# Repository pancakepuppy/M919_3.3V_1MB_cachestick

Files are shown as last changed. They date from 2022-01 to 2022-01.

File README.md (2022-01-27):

# M919_3.3V_1MB_cachestick
A 3.3V 1MB cache stick design for PCChips M919

(This design is only to be used with 3.3V processors. 5V/4V CPUs will violate the Absolute Maximum Terminal Voltage Relative to GND of the 3.3V SRAM chips which will likely result in permanent damage of the cache ICs.)

Design uses center power 0.400" 32-SOJ 128Kx8 3.3V SRAMs, which are available in speed grades of 8(less common)/10/12/15ns from several vendors. 
These parts should all fit this criteria:

71V124SA10/12/15Y

CY7C1019DV33-10VXI

CY7C1019BV33-10/12/15V

CY7C1019CV33-10/12/15V

IS63LV1024-8/10/12K

AS7C31025B-10/12/15J

AS7C31025C-10J

Bill of materials only has 3 different parts on it:

  Qty 18 - 0603 0.1uF 6.3V+ ceramic capacitors
  
  Qty 9 - SRAM parts as described above
  
  Qty 4 - 0603 33ohm convex 4resistor array
  
If you're experienced at hand soldering, the module is buildable this way (that's how I've built mine so far!)

I've been testing the module design with a 5x86-P75 (133MHz) at fastest L2 and DRAM settings and it has been very stable, running a number of DOS and Win95 benchmarks and tests (such as Quake, Doom, cachechk, Winstone 96, CPUmark99, Super PI) with no issues. 

If you want to have boards made with JLCPCB, upload the "UPLOAD_THIS_ZIP.zip" file in the /plotted_JLCsettings/ directory. It has the gerbers and drill files with their recommended plotting settings. Otherwise, plot however your board house recommends!

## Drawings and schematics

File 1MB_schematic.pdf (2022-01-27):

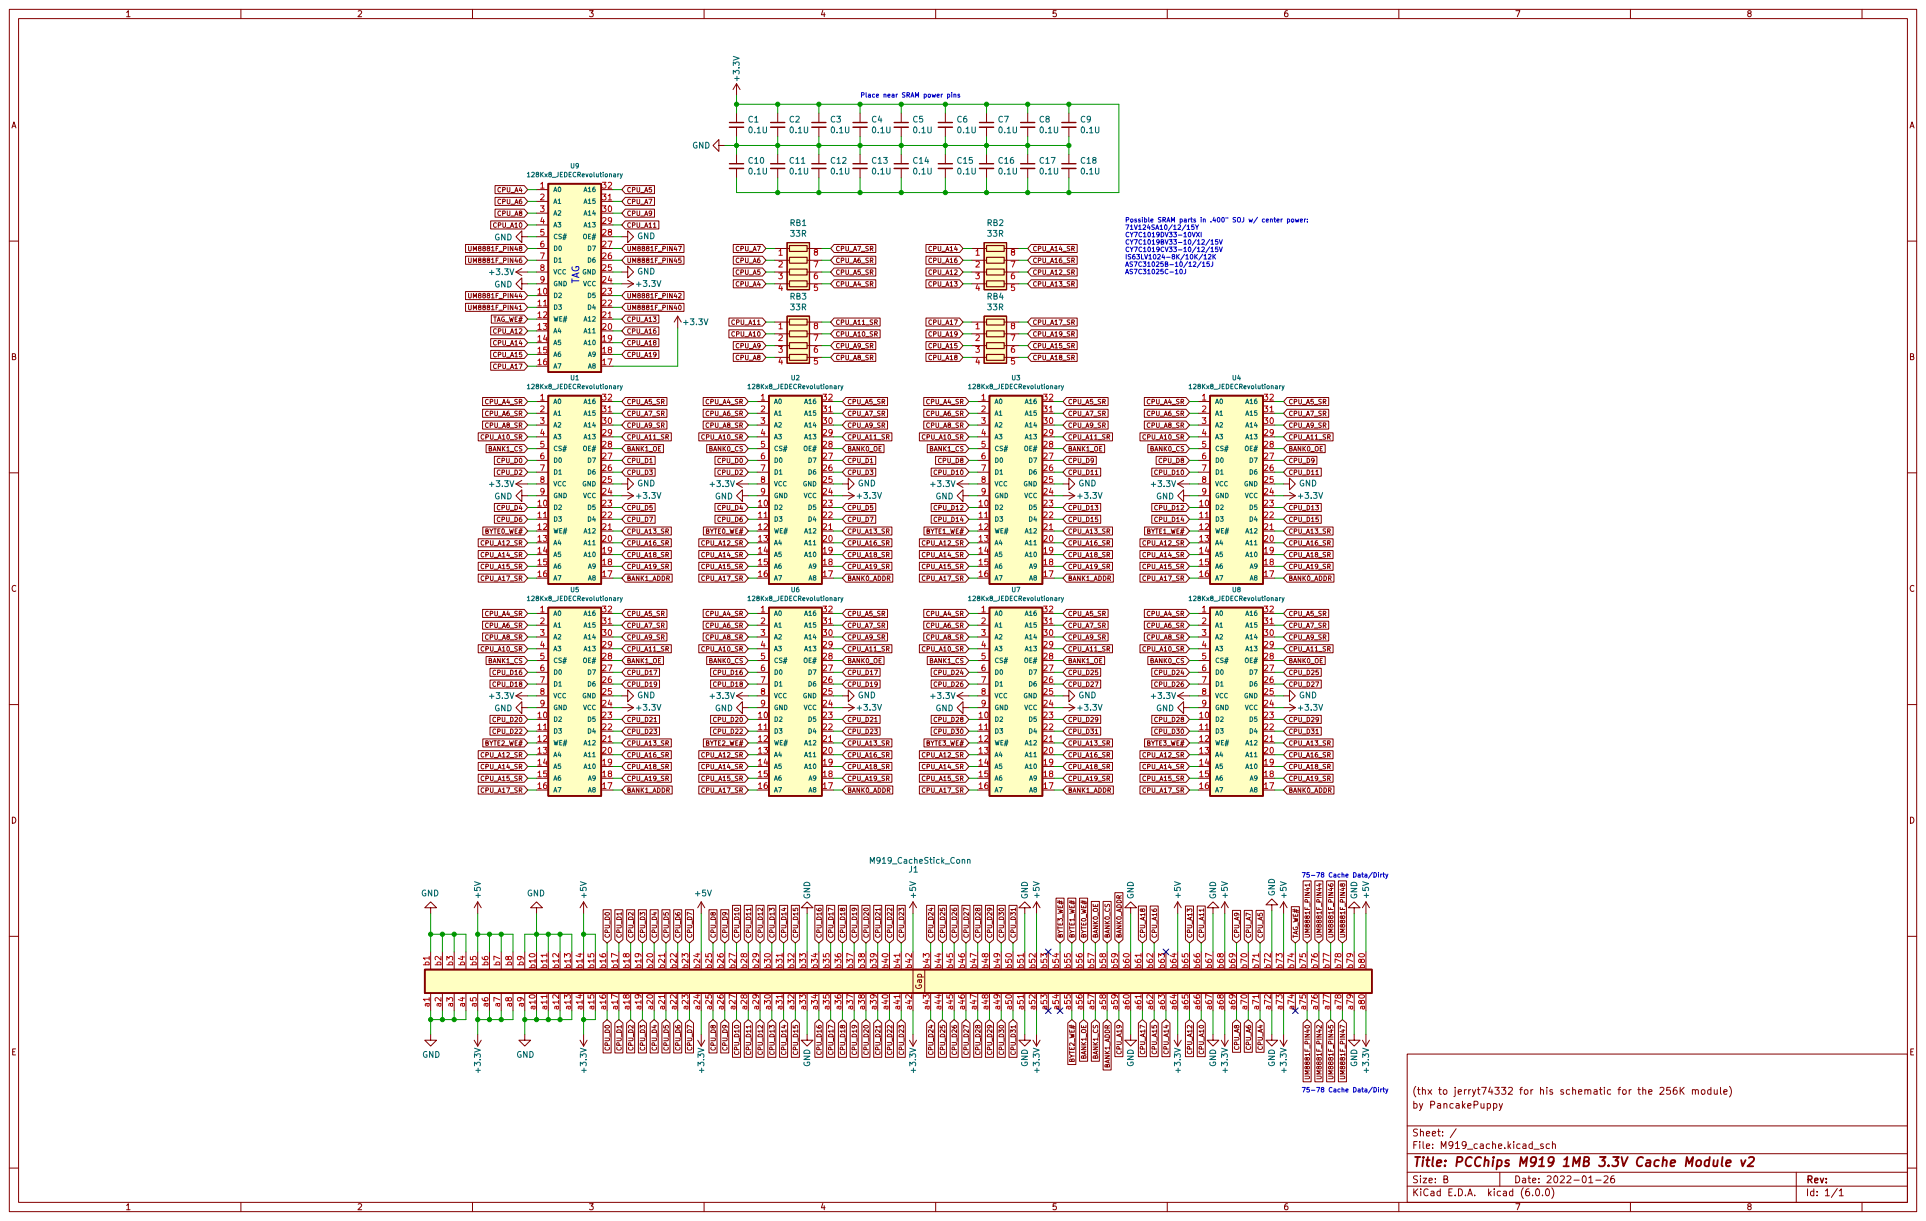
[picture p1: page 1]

File: M919_cache.kicad_sch Sheet: / by PancakePuppy

Id: 1/1 Title: PCChips M919 1MB 3.3V Cache Module v2

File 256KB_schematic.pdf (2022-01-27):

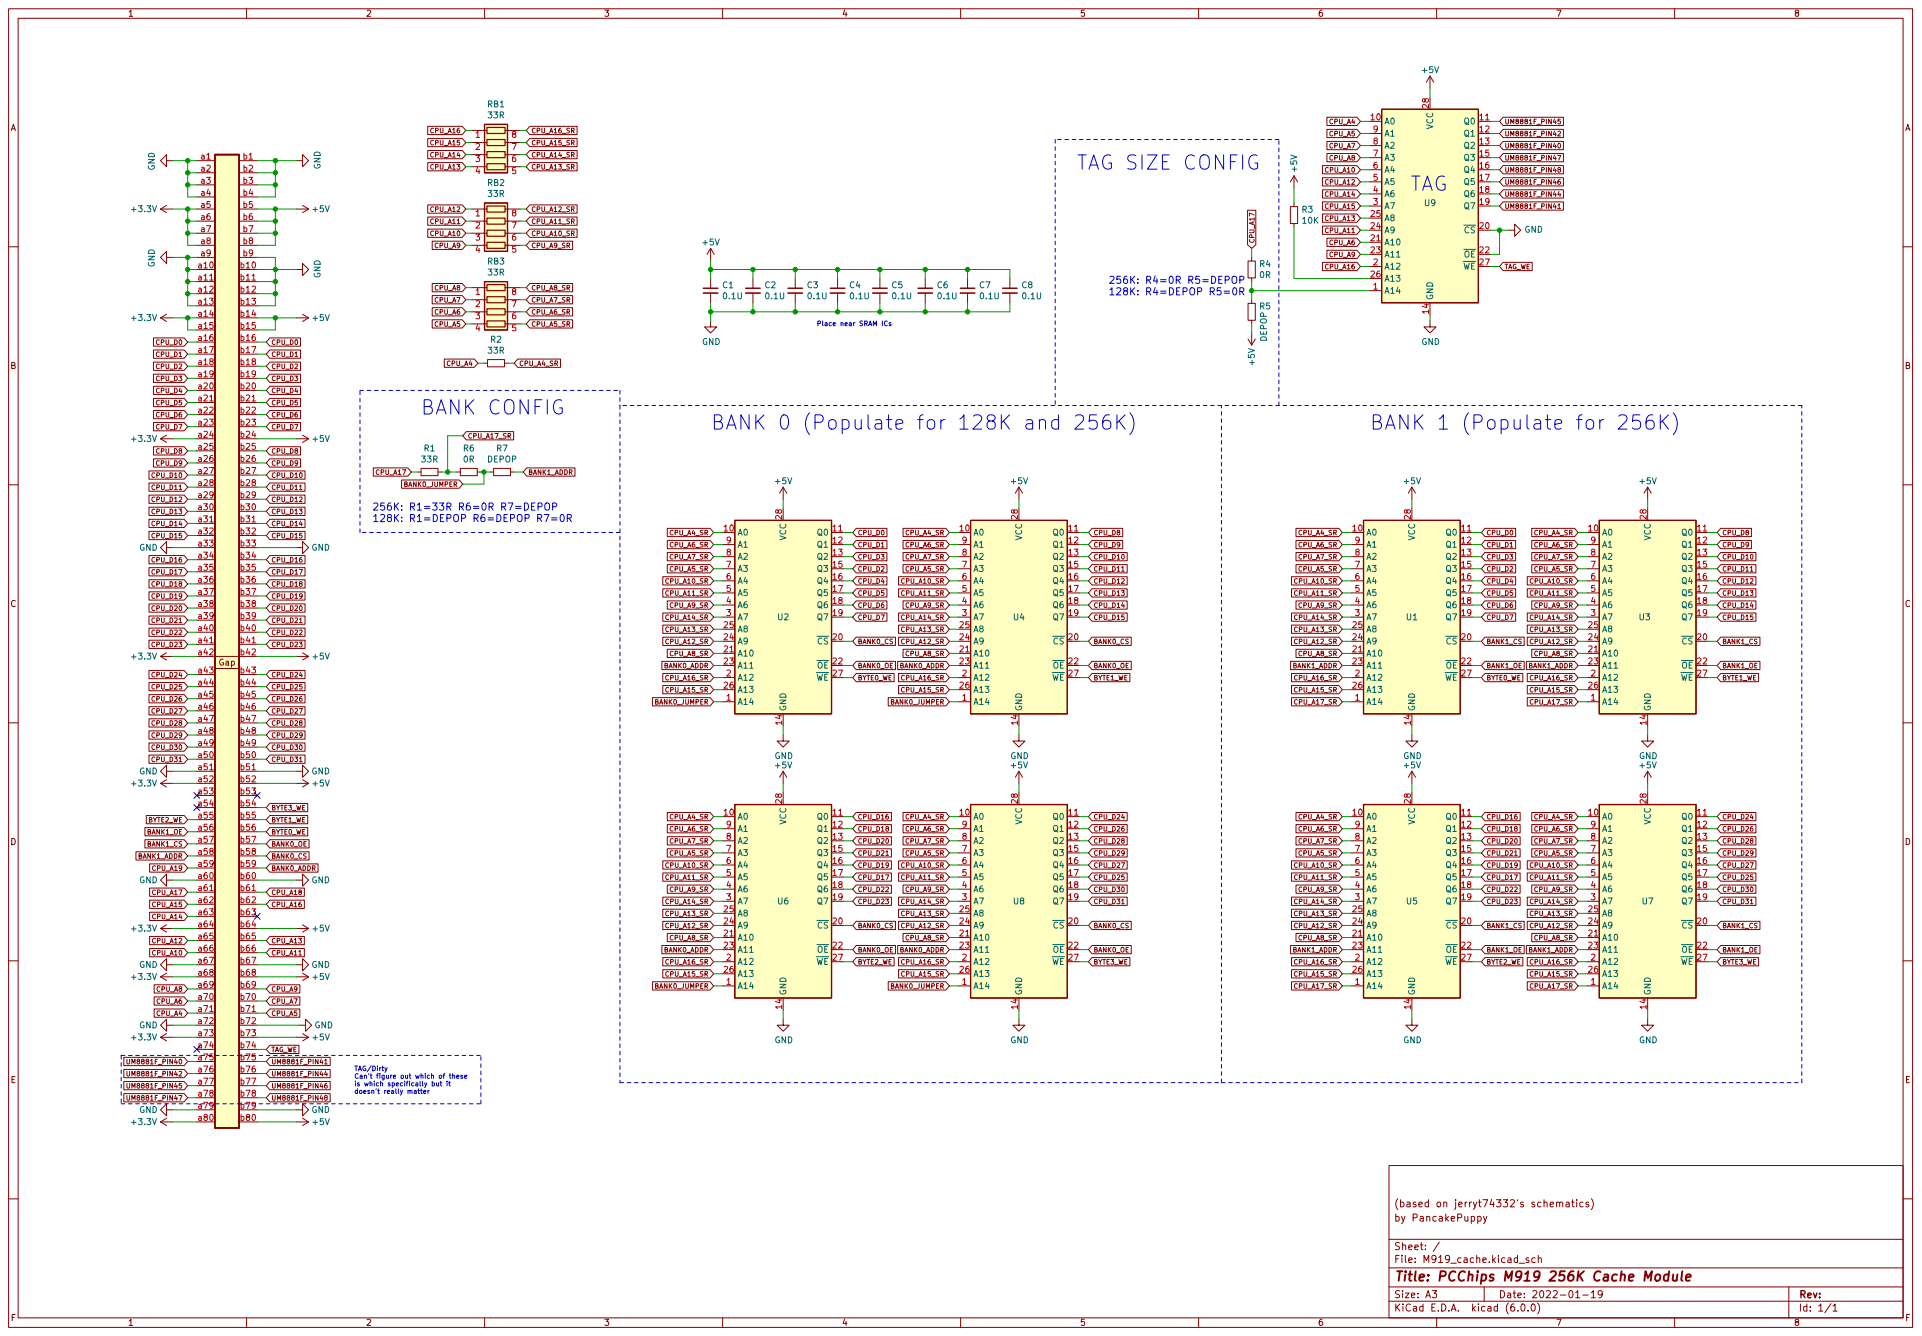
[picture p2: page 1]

(based on jerryt74332's schematics) GND

is which specifically but it doesn't really matter BANK CONFIG

TAG/Dirty Can't figure out which of these

File: M919_cache.kicad_sch Sheet: / by PancakePuppy

Id: 1/1 Title: PCChips M919 256K Cache Module

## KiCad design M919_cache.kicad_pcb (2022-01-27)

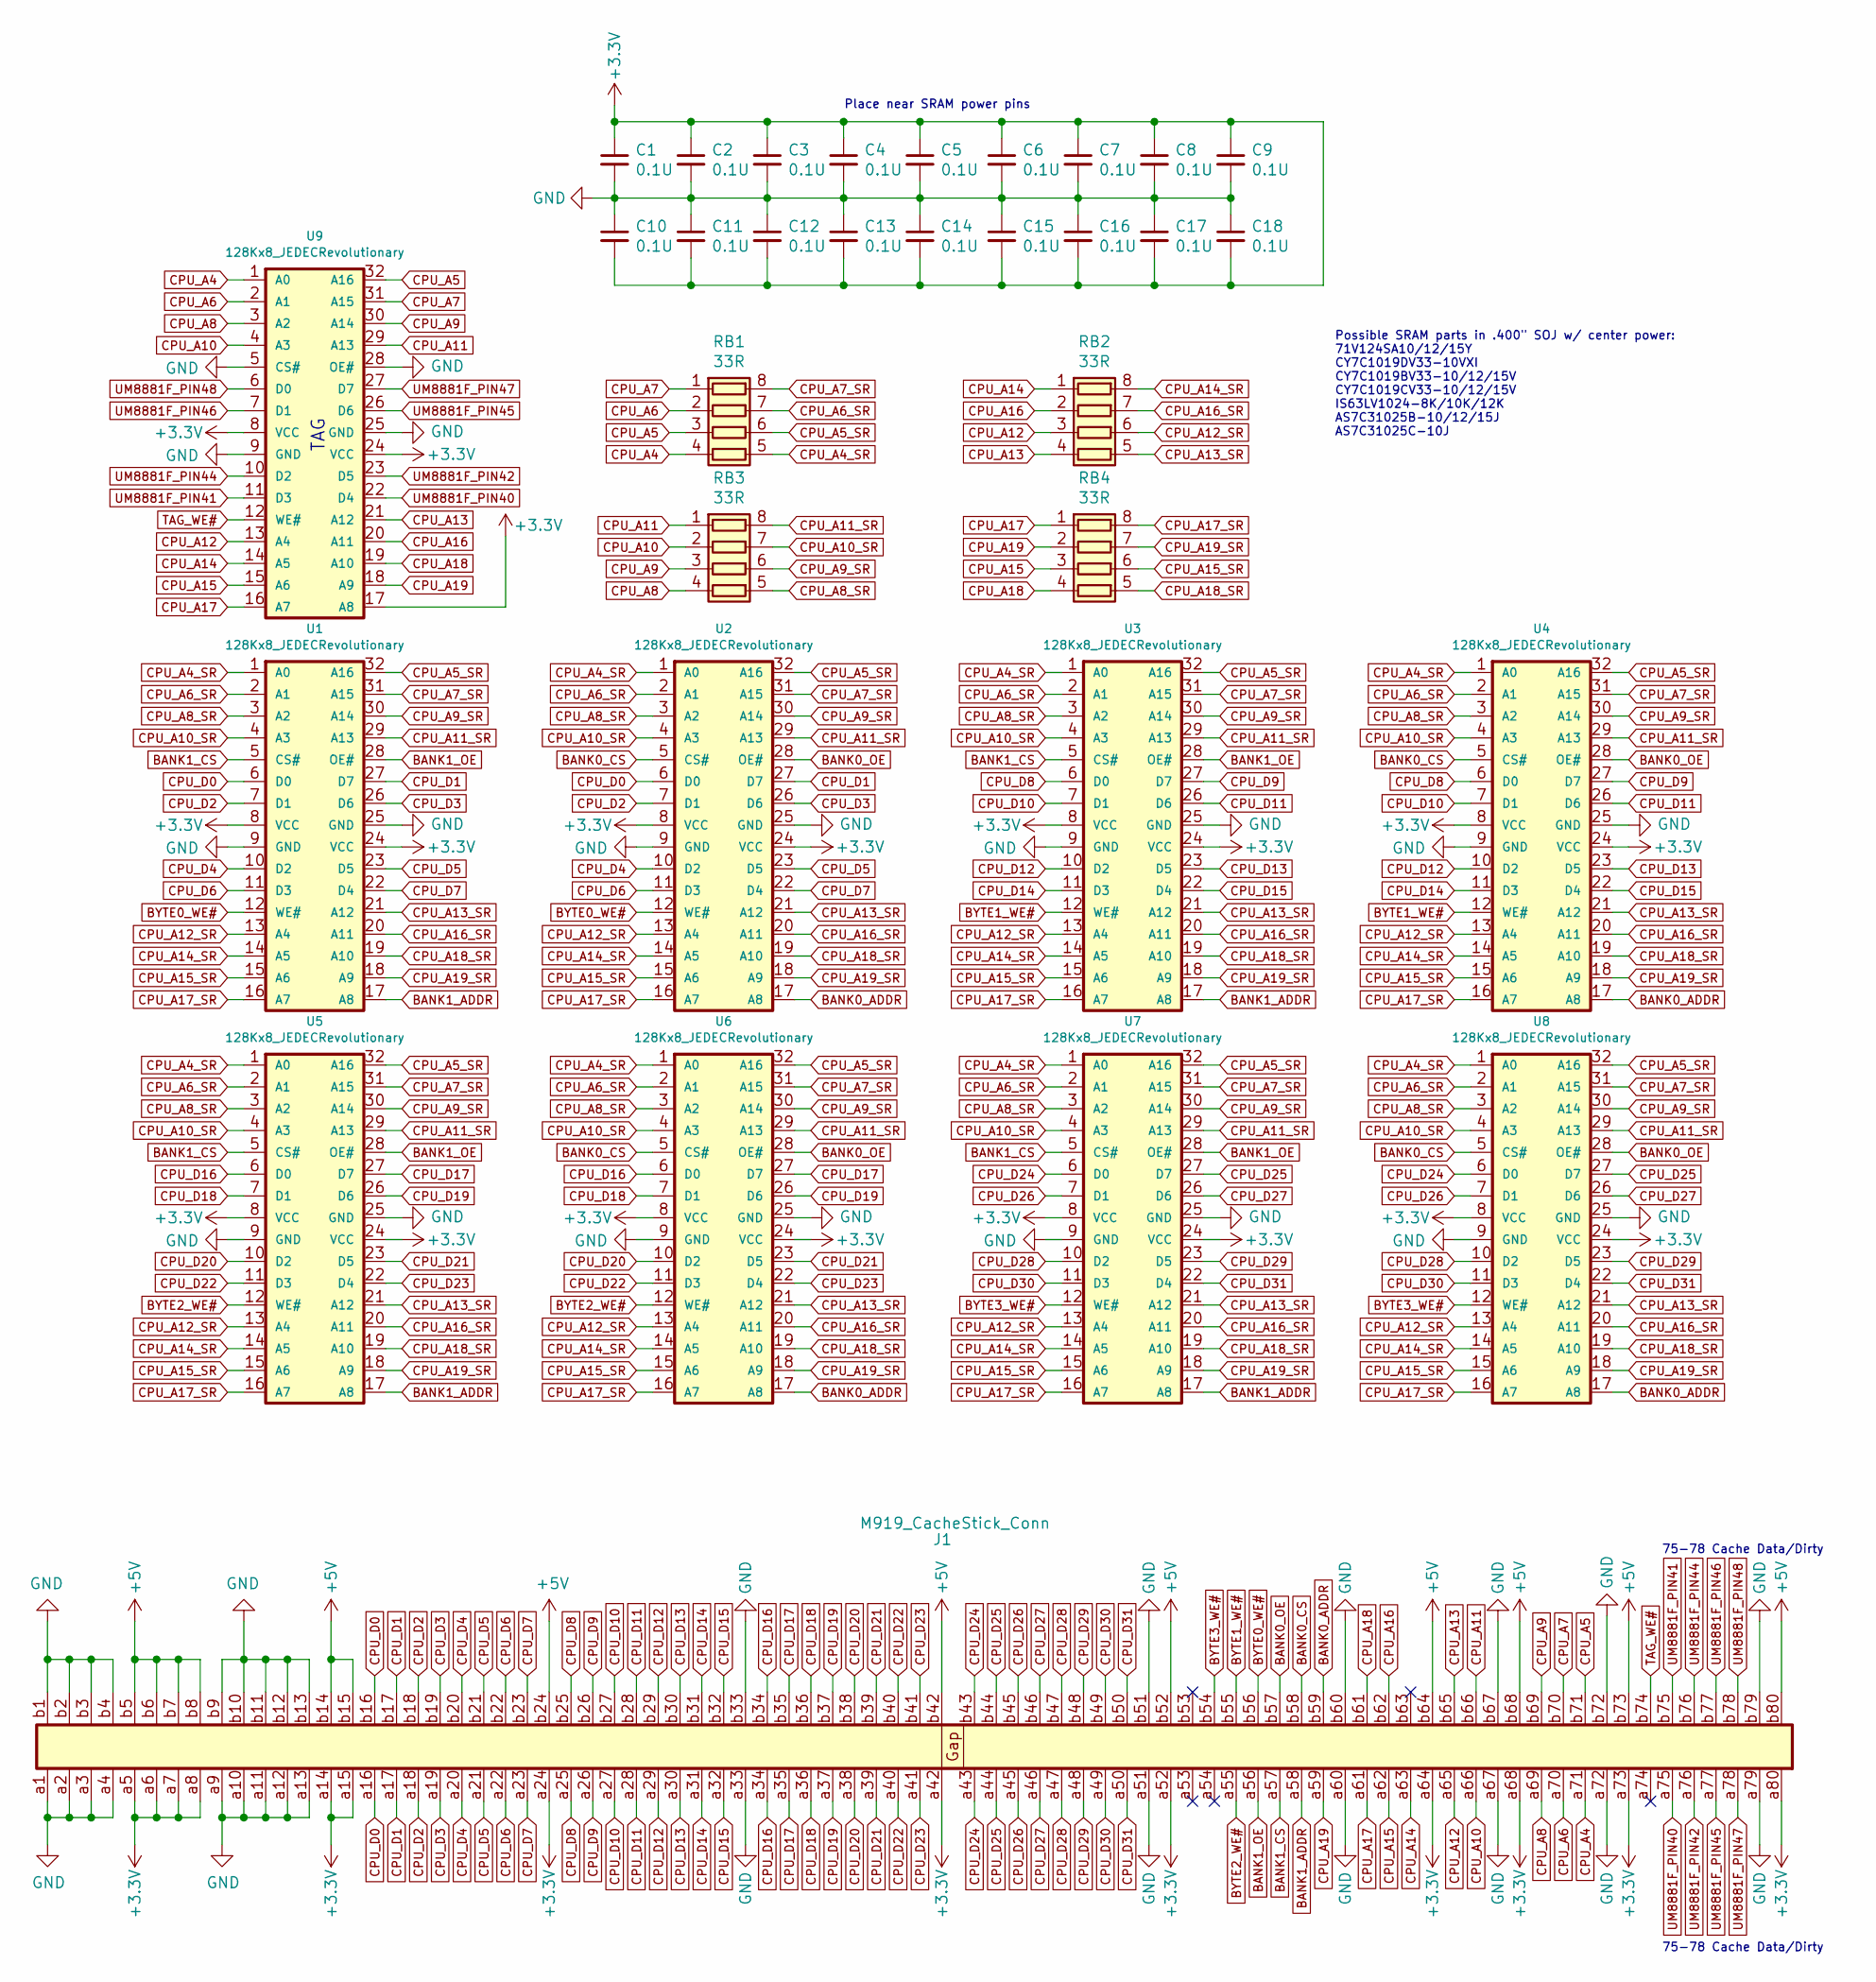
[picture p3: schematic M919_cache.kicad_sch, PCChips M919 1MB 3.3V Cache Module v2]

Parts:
C1, C2, C3, C4, C5, C6, C7, C8, C9, C10, C11, C12, C13, C14, C15, C16, C17, C18: 0.1U; C_0603_1608Metric
J1: M919_CacheStick_Conn; M919_cache_edgeconn
RB1, RB2, RB3, RB4: 33R; R_Array_Convex_4x0603
U1, U2, U3, U4, U5, U6, U7, U8, U9: 128Kx8_JEDECRevolutionary; 32-SOJ_400mil

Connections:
+3V3: C1.1, C2.1, C3.1, C4.1, C5.1, C6.1, C7.1, C8.1, C9.1, C10.2, C11.2, C12.2, C13.2, C14.2, C15.2, C16.2, C17.2, C18.2, J1.a5, J1.a6, J1.a7, J1.a8, J1.a14, J1.a15, J1.a24, J1.a42, J1.a52, J1.a64, J1.a68, J1.a73, J1.a80, U1.8 (VCC), U1.24 (VCC), U2.8 (VCC), U2.24 (VCC), U3.8 (VCC), U3.24 (VCC), U4.8 (VCC), U4.24 (VCC), U5.8 (VCC), U5.24 (VCC), U6.8 (VCC), U6.24 (VCC), U7.8 (VCC), U7.24 (VCC), U8.8 (VCC), U8.24 (VCC), U9.8 (VCC), U9.17 (A8), U9.24 (VCC)
+5V: J1.b5, J1.b6, J1.b7, J1.b8, J1.b14, J1.b15, J1.b24, J1.b42, J1.b52, J1.b64, J1.b68, J1.b73, J1.b80
BANK0_ADDR: J1.b59, U2.17 (A8), U4.17 (A8), U6.17 (A8), U8.17 (A8)
BANK0_CS: J1.b58, U2.5 (CS#), U4.5 (CS#), U6.5 (CS#), U8.5 (CS#)
BANK0_OE: J1.b57, U2.28 (OE#), U4.28 (OE#), U6.28 (OE#), U8.28 (OE#)
BANK1_ADDR: J1.a58, U1.17 (A8), U3.17 (A8), U5.17 (A8), U7.17 (A8)
BANK1_CS: J1.a57, U1.5 (CS#), U3.5 (CS#), U5.5 (CS#), U7.5 (CS#)
BANK1_OE: J1.a56, U1.28 (OE#), U3.28 (OE#), U5.28 (OE#), U7.28 (OE#)
BYTE0_WE#: J1.b56, U1.12 (WE#), U2.12 (WE#)
BYTE1_WE#: J1.b55, U3.12 (WE#), U4.12 (WE#)
BYTE2_WE#: J1.a55, U5.12 (WE#), U6.12 (WE#)
BYTE3_WE#: J1.b54, U7.12 (WE#), U8.12 (WE#)
CPU_A4: J1.a71, RB1.4 (R4.1), U9.1 (A0)
CPU_A4_SR: RB1.5 (R4.2), U1.1 (A0), U2.1 (A0), U3.1 (A0), U4.1 (A0), U5.1 (A0), U6.1 (A0), U7.1 (A0), U8.1 (A0)
CPU_A5: J1.b71, RB1.3 (R3.1), U9.32 (A16)
CPU_A5_SR: RB1.6 (R3.2), U1.32 (A16), U2.32 (A16), U3.32 (A16), U4.32 (A16), U5.32 (A16), U6.32 (A16), U7.32 (A16), U8.32 (A16)
CPU_A6: J1.a70, RB1.2 (R2.1), U9.2 (A1)
CPU_A6_SR: RB1.7 (R2.2), U1.2 (A1), U2.2 (A1), U3.2 (A1), U4.2 (A1), U5.2 (A1), U6.2 (A1), U7.2 (A1), U8.2 (A1)
CPU_A7: J1.b70, RB1.1 (R1.1), U9.31 (A15)
CPU_A7_SR: RB1.8 (R1.2), U1.31 (A15), U2.31 (A15), U3.31 (A15), U4.31 (A15), U5.31 (A15), U6.31 (A15), U7.31 (A15), U8.31 (A15)
CPU_A8: J1.a69, RB3.4 (R4.1), U9.3 (A2)
CPU_A8_SR: RB3.5 (R4.2), U1.3 (A2), U2.3 (A2), U3.3 (A2), U4.3 (A2), U5.3 (A2), U6.3 (A2), U7.3 (A2), U8.3 (A2)
CPU_A9: J1.b69, RB3.3 (R3.1), U9.30 (A14)
CPU_A9_SR: RB3.6 (R3.2), U1.30 (A14), U2.30 (A14), U3.30 (A14), U4.30 (A14), U5.30 (A14), U6.30 (A14), U7.30 (A14), U8.30 (A14)
CPU_A10: J1.a66, RB3.2 (R2.1), U9.4 (A3)
CPU_A10_SR: RB3.7 (R2.2), U1.4 (A3), U2.4 (A3), U3.4 (A3), U4.4 (A3), U5.4 (A3), U6.4 (A3), U7.4 (A3), U8.4 (A3)
CPU_A11: J1.b66, RB3.1 (R1.1), U9.29 (A13)
CPU_A11_SR: RB3.8 (R1.2), U1.29 (A13), U2.29 (A13), U3.29 (A13), U4.29 (A13), U5.29 (A13), U6.29 (A13), U7.29 (A13), U8.29 (A13)
CPU_A12: J1.a65, RB2.3 (R3.1), U9.13 (A4)
CPU_A12_SR: RB2.6 (R3.2), U1.13 (A4), U2.13 (A4), U3.13 (A4), U4.13 (A4), U5.13 (A4), U6.13 (A4), U7.13 (A4), U8.13 (A4)
CPU_A13: J1.b65, RB2.4 (R4.1), U9.21 (A12)
CPU_A13_SR: RB2.5 (R4.2), U1.21 (A12), U2.21 (A12), U3.21 (A12), U4.21 (A12), U5.21 (A12), U6.21 (A12), U7.21 (A12), U8.21 (A12)
CPU_A14: J1.a63, RB2.1 (R1.1), U9.14 (A5)
CPU_A14_SR: RB2.8 (R1.2), U1.14 (A5), U2.14 (A5), U3.14 (A5), U4.14 (A5), U5.14 (A5), U6.14 (A5), U7.14 (A5), U8.14 (A5)
CPU_A15: J1.a62, RB4.3 (R3.1), U9.15 (A6)
CPU_A15_SR: RB4.6 (R3.2), U1.15 (A6), U2.15 (A6), U3.15 (A6), U4.15 (A6), U5.15 (A6), U6.15 (A6), U7.15 (A6), U8.15 (A6)
CPU_A16: J1.b62, RB2.2 (R2.1), U9.20 (A11)
CPU_A16_SR: RB2.7 (R2.2), U1.20 (A11), U2.20 (A11), U3.20 (A11), U4.20 (A11), U5.20 (A11), U6.20 (A11), U7.20 (A11), U8.20 (A11)
CPU_A17: J1.a61, RB4.1 (R1.1), U9.16 (A7)
CPU_A17_SR: RB4.8 (R1.2), U1.16 (A7), U2.16 (A7), U3.16 (A7), U4.16 (A7), U5.16 (A7), U6.16 (A7), U7.16 (A7), U8.16 (A7)
CPU_A18: J1.b61, RB4.4 (R4.1), U9.19 (A10)
CPU_A18_SR: RB4.5 (R4.2), U1.19 (A10), U2.19 (A10), U3.19 (A10), U4.19 (A10), U5.19 (A10), U6.19 (A10), U7.19 (A10), U8.19 (A10)
CPU_A19: J1.a59, RB4.2 (R2.1), U9.18 (A9)
CPU_A19_SR: RB4.7 (R2.2), U1.18 (A9), U2.18 (A9), U3.18 (A9), U4.18 (A9), U5.18 (A9), U6.18 (A9), U7.18 (A9), U8.18 (A9)
CPU_D0: J1.a16, J1.b16, U1.6 (D0), U2.6 (D0)
CPU_D1: J1.a17, J1.b17, U1.27 (D7), U2.27 (D7)
CPU_D2: J1.a18, J1.b18, U1.7 (D1), U2.7 (D1)
CPU_D3: J1.a19, J1.b19, U1.26 (D6), U2.26 (D6)
CPU_D4: J1.a20, J1.b20, U1.10 (D2), U2.10 (D2)
CPU_D5: J1.a21, J1.b21, U1.23 (D5), U2.23 (D5)
CPU_D6: J1.a22, J1.b22, U1.11 (D3), U2.11 (D3)
CPU_D7: J1.a23, J1.b23, U1.22 (D4), U2.22 (D4)
CPU_D8: J1.a25, J1.b25, U3.6 (D0), U4.6 (D0)
CPU_D9: J1.a26, J1.b26, U3.27 (D7), U4.27 (D7)
CPU_D10: J1.a27, J1.b27, U3.7 (D1), U4.7 (D1)
CPU_D11: J1.a28, J1.b28, U3.26 (D6), U4.26 (D6)
CPU_D12: J1.a29, J1.b29, U3.10 (D2), U4.10 (D2)
CPU_D13: J1.a30, J1.b30, U3.23 (D5), U4.23 (D5)
CPU_D14: J1.a31, J1.b31, U3.11 (D3), U4.11 (D3)
CPU_D15: J1.a32, J1.b32, U3.22 (D4), U4.22 (D4)
CPU_D16: J1.a34, J1.b34, U5.6 (D0), U6.6 (D0)
CPU_D17: J1.a35, J1.b35, U5.27 (D7), U6.27 (D7)
CPU_D18: J1.a36, J1.b36, U5.7 (D1), U6.7 (D1)
CPU_D19: J1.a37, J1.b37, U5.26 (D6), U6.26 (D6)
CPU_D20: J1.a38, J1.b38, U5.10 (D2), U6.10 (D2)
CPU_D21: J1.a39, J1.b39, U5.23 (D5), U6.23 (D5)
CPU_D22: J1.a40, J1.b40, U5.11 (D3), U6.11 (D3)
CPU_D23: J1.a41, J1.b41, U5.22 (D4), U6.22 (D4)
CPU_D24: J1.a43, J1.b43, U7.6 (D0), U8.6 (D0)
CPU_D25: J1.a44, J1.b44, U7.27 (D7), U8.27 (D7)
CPU_D26: J1.a45, J1.b45, U7.7 (D1), U8.7 (D1)
CPU_D27: J1.a46, J1.b46, U7.26 (D6), U8.26 (D6)
CPU_D28: J1.a47, J1.b47, U7.10 (D2), U8.10 (D2)
CPU_D29: J1.a48, J1.b48, U7.23 (D5), U8.23 (D5)
CPU_D30: J1.a49, J1.b49, U7.11 (D3), U8.11 (D3)
CPU_D31: J1.a50, J1.b50, U7.22 (D4), U8.22 (D4)
GND: C1.2, C2.2, C3.2, C4.2, C5.2, C6.2, C7.2, C8.2, C9.2, C10.1, C11.1, C12.1, C13.1, C14.1, C15.1, C16.1, C17.1, C18.1, J1.a1, J1.a2, J1.a3, J1.a4, J1.a9, J1.a10, J1.a11, J1.a12, J1.a13, J1.a33, J1.a51, J1.a60, J1.a67, J1.a72, J1.a79, J1.b1, J1.b2, J1.b3, J1.b4, J1.b9, J1.b10, J1.b11, J1.b12, J1.b13, J1.b33, J1.b51, J1.b60, J1.b67, J1.b72, J1.b79, U1.9 (GND), U1.25 (GND), U2.9 (GND), U2.25 (GND), U3.9 (GND), U3.25 (GND), U4.9 (GND), U4.25 (GND), U5.9 (GND), U5.25 (GND), U6.9 (GND), U6.25 (GND), U7.9 (GND), U7.25 (GND), U8.9 (GND), U8.25 (GND), U9.5 (CS#), U9.9 (GND), U9.25 (GND), U9.28 (OE#)
TAG_WE#: J1.b74, U9.12 (WE#)
UM8881F_PIN40: J1.a75, U9.22 (D4)
UM8881F_PIN41: J1.b75, U9.11 (D3)
UM8881F_PIN42: J1.a76, U9.23 (D5)
UM8881F_PIN44: J1.b76, U9.10 (D2)
UM8881F_PIN45: J1.a77, U9.26 (D6)
UM8881F_PIN46: J1.b77, U9.7 (D1)
UM8881F_PIN47: J1.a78, U9.27 (D7)
UM8881F_PIN48: J1.b78, U9.6 (D0)

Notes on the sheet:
75-78 Cache Data/Dirty
Possible SRAM parts in .400" SOJ w/ center power: 71V124SA10/12/15Y CY7C1019DV33-10VXI CY7C1019BV33-10/12/15V CY7C1019CV33-10/12/15V IS63LV1024-8K/10K/12K AS7C31025B-10/12/15J AS7C31025C-10J
Place near SRAM power pins
TAG

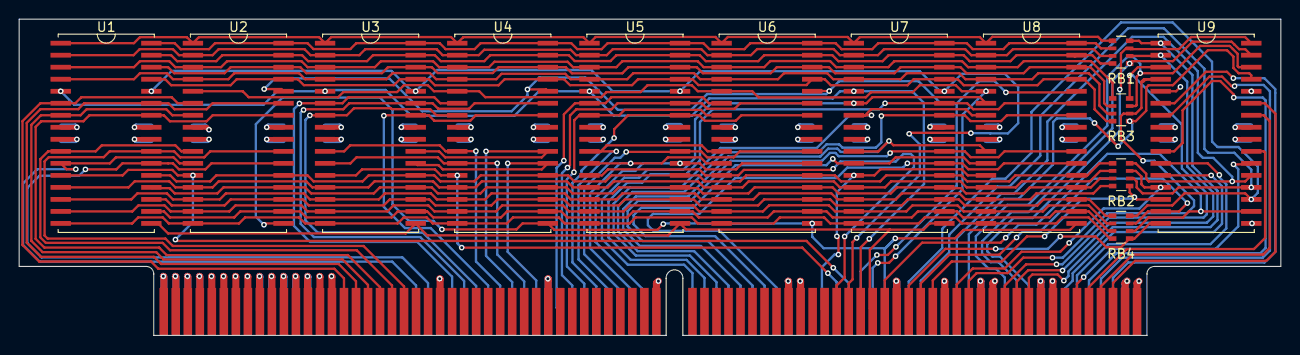
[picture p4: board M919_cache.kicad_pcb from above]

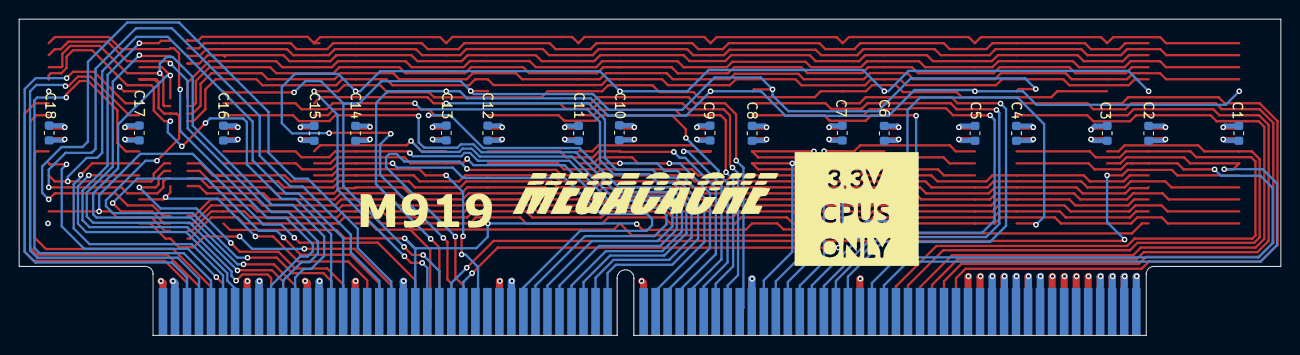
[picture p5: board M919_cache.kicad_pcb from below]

Board: 4 copper layers, 133.4 x 33.4 mm, 32 parts (18 on the bottom side), 86 nets.
